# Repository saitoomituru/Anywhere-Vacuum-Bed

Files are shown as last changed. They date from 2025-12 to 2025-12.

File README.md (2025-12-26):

# どこでもバキュームベット
*Anywhere Vacuum Bed / Rubber Vacuum Bed*

*Anywhere Vacuum Bed* is an open, vacuum-fixture style project you can build anywhere with just a household vacuum and a bag—no specialty pumps needed.

掃除機と袋があれば、どこでも簡易的な真空固定・圧縮ができる
オープンソースのバキューム治具です。

With a regular shop vac and a bag, you get quick vacuum clamping or compression anywhere. The whole design is open source.

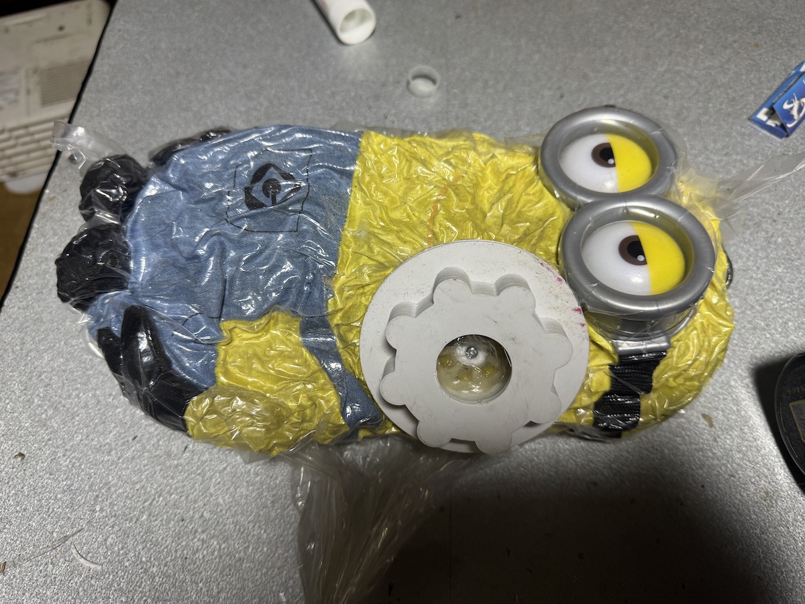
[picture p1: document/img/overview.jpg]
overview


3Dプリンタ（FDM）で再現可能。
専用シートや高価な真空ポンプは不要です。

Reproducible on common FDM printers. No custom sheets or pricey vacuum pumps required.

▶️ Demo Video (2 min)  
https://youtube.com/shorts/qQuK8cIHQdQ?si=-0dno3jXxC5wWSed

---

## 特徴

- 掃除機・ブロワ対応（真空ポンプ不要）
- 袋（PE / PP / PVC / TPU など）を消耗品として使用
- 伸びる素材・伸びない素材の両対応
- 薄く柔らかい素材でも流路を塞がない裏側リブ構造
- 逆流防止弁内蔵（初速・保持の両立）
- 工具不要で解除可能
- FDM積層の気密問題を**シリコングリス前提**で解決
- 年齢・用途を限定しない構造（使用は自己責任）

**Features (California/Texas US English)**

- Works with household vacuums and blowers—no dedicated pump.
- Uses common bags (PE/PP/PVC/TPU, etc.) as consumables.
- Handles stretchy and non-stretch films alike.
- Backside ribs keep airflow paths open even with thin, soft materials.
- Built-in check valve balances fast start-up with reliable holding.
- Release without tools.
- Airtightness assumes silicone grease to tame FDM layer leakage.
- Open form factor for all ages and uses—always at your own risk.

---

## 想定用途

- 簡易バキュームベッド / 仮固定治具
- 収納・圧縮（衣類・ぬいぐるみ等）
- ゴム・ラバー・TPU・フィルム等の柔軟素材固定
- 塗装・接着・成形前の仮固定
- 教育・FabLab・DIY用途
- 個人利用・研究用途

**Intended Uses (CA/TX English)**

- Quick vacuum bed or temporary jigging.
- Storage and compression for clothes, plush toys, and similar items.
- Holding flexible materials such as rubber, TPU, and films.
- Temporary holding before painting, bonding, or forming.
- Education, FabLab, and DIY settings.
- Personal projects and research.

⚠ **人体・物体を問わず、使用はすべて自己責任です。**
⚠ 本設計は医療・安全認証を意図したものではありません。

⚠ **Use at your own risk for people or objects.**
⚠ This design is not intended for medical or safety certification.

---

## クイックリンク（最初に読む）

- 🔧 **組み立て方法（Assembly）**
  → [`document/howto/assembly.md`](document/howto/assembly.md)

- 🧰 **使い方：伸縮性のない一般ゴミ袋**
  → [`document/howto/use_trashbag.md`](document/howto/use_trashbag.md)

- 📐 **FreeCAD 全体アセンブリ**
  → [`Assembly.FCStd`](Assembly.FCStd)

**Quick Links (read first)**

- 🔧 Assembly guide → [`document/howto/assembly.md`](document/howto/assembly.md)
- 🧰 Using non-stretch trash bags → [`document/howto/use_trashbag.md`](document/howto/use_trashbag.md)
- 📐 Full FreeCAD assembly → [`Assembly.FCStd`](Assembly.FCStd)

---

## ディレクトリ構成

```text
/
├─ README.md
├─ Assembly.FCStd              # 全体アセンブリ（FreeCAD）
├─ Bild/
│  └─ Assy/
│     └─ *.FCStd               # 各パーツ（FreeCAD）
├─ stage/
│  └─ stl/
│     └─ *.stl                 # 3Dプリント用STL
└─ document/
   ├─ img/                     # 写真・図解
   └─ howto/                   # 作り方・使用方法
      ├─ assembly.md
      └─ use_trashbag.md
```

---

## 仕組みについて（設計思想）

### 裏側リブ構造
裏側の放射リブ形状は、

- 薄い素材が吸着時に流路を塞がない
- 真空初速を維持
- 完全密閉にならず自然解除しやすい

という **安全側に倒した流路保持構造**です。

**Design Approach (CA/TX English)**

### Backside rib structure
The radiating ribs on the underside are sized so that thin materials don’t choke the airflow, startup vacuum speed stays quick, and the system can gently vent instead of locking shut—prioritizing safe flow retention.

---

## シールについて（FDM前提）

本設計では **シリコングリスの使用を前提**としています。

- FDM積層による微細リーク対策
- 材料・プリンタ個体差の吸収
- 分解・清掃・再利用が容易

**Sealing (FDM-first perspective)**

The design assumes silicone grease from the start. It handles micro-leaks from FDM layers, smooths out printer/material variances, and keeps teardown and cleaning simple.

### 塗布箇所
- 外周の袋シール溝
- **中央の逆流防止ゴム面（薄塗り）**

※ 潤滑ではなく **気密補助目的**です。

### Where to apply
- Perimeter groove that seals the bag.
- **Center check-valve rubber face (light coat).**

Note: This is for airtightness support, not for lubrication.

---

## 袋の取り付け方法（2通り）

### ① 伸びる素材（PE / TPU など）
1. 袋に **約52mmの穴**を開ける
2. 本体に袋を挟み、ネジで固定

### ② 伸びない素材（PP / 硬質PVC 等）
1. **袋に下穴は開けない**
2. そのまま本体に袋を挟んで固定
3. バキューム前に
   **中央吸入口に指を入れて袋を破る**
4. そのまま吸引開始

※ 中央弁構造により、
　破断後も袋が吸い込まれにくい設計です。

**How to attach bags (two options)**

### 1) Stretchy materials (PE/TPU, etc.)
1. Punch a **~52 mm hole** in the bag.
2. Clamp it to the body and tighten the screws.

### 2) Non-stretch materials (PP, rigid PVC, etc.)
1. **Do not pre-drill** the bag.
2. Clamp it to the body as-is.
3. Right before vacuuming, **poke the center inlet with a finger to tear the film.**
4. Start vacuuming immediately.

The center valve design keeps the torn bag from getting sucked in.

---

## 使用・解除方法（概要）

### 使用
1. 袋に対象物を入れる
2. 袋の口を縛る
3. 掃除機で吸引

### 解除
- ネジを外す
- 袋の端をつまむ
（工具不要）

**Use / Release (overview)**

### Use
1. Place the item in the bag.
2. Tie the bag closed.
3. Pull vacuum with a household vacuum.

### Release
- Remove the screws.
- Pinch the bag edge to vent (no tools needed).

---

## 3Dプリントについて

- 推奨方式：FDM
- 材質：PLA / PETG / ABS（用途に応じて）
- 機能面（シール面）は **ビルドプレート直置き推奨**
- サポート不要設計

**3D printing notes**

- Recommended process: FDM.
- Materials: PLA / PETG / ABS depending on use.
- Functional sealing faces: **print flat on the build plate**.
- Designed to avoid supports.

---

## FDM造形テック（サポート不要設計）

本設計では、**裏側リブおよび溝構造の幅をすべて 5mm 以下**に制限しています。

これは一般的なFDM 3Dプリンタにおいて、

- サポート材を使用せずに
- 安定したオーバーハング／ブリッジ造形が可能

という **実運用での再現性**を最優先した設計判断です。

**FDM build strategy (supportless)**

All underside rib and groove widths stay at or below 5 mm. On typical FDM printers, that means you can bridge and overhang without supports while keeping real-world repeatability as the top priority.

### この設計によるメリット

- サポート除去が不要
  → 表面荒れ・寸法誤差・シール面破壊を防止
- 印刷後の後処理が不要
  → プリント後すぐに使用可能
- シール面の平面性を確保
  → 真空用途における気密性向上

### Benefits of this approach

- No support removal → avoids surface roughness, dimensional drift, and seal-surface damage.
- No post-processing → use the print right away.
- Flat sealing surfaces → better airtightness for vacuum duty.

### 設計思想（FDM前提）

- 真空流路として十分な断面を確保しつつ
- 「FDMで確実に橋渡しできる寸法」を上限条件として採用

この 5mm という数値は理論値ではなく、

- ノズル径：0.4mm  
- レイヤー高：0.2〜0.28mm  
- 家庭用FDMプリンタ

という **一般的な環境での実証ベース**の設計です。

真空用途のため、微細な糸引きや軽微なたわみは
**機能的に問題にならない**ことも考慮しています。

むしろサポートを使用することで、

- シール面の精度低下
- 表面の荒れ
- 再現性の低下

が起きやすいため、本設計では **サポート不要を前提**としています。

### Design mindset (FDM-first)

- Cross-sections stay big enough for vacuum flow while capped at dimensions that bridge reliably on FDM.
- The 5 mm limit is practical, not theoretical—based on common home FDM setups (0.4 mm nozzle, 0.2–0.28 mm layers).
- For vacuum use, small strings or slight sag usually don’t matter.
- Using supports tends to hurt seal precision, roughen surfaces, and lower repeatability, so the design assumes no supports.

---

## ライセンス

本プロジェクトは **CERN Open Hardware Licence Version 2 – Permissive (CERN-OHL-P)**
の下で公開されています。

**License**

Released under the **CERN Open Hardware Licence Version 2 – Permissive (CERN-OHL-P)**.

- 商用利用可
- 改変可
- 再配布可
- 派生物の公開義務なし

⚠ **本設計の使用により生じた事故・損害について、作者は一切の責任を負いません。**

ライセンス全文：  
https://ohwr.org/cern_ohl_p_v2.txt

---

## 名前について

「どこでもバキュームベット」は  
**ドラえもん道具的に、誰でも・どこでも使える道具**  
という思想から名付けています。

用途・文脈・分野は限定していません。

---

## English (Short)

**Anywhere Vacuum Bed**  
An open-source vacuum fixture using a vacuum cleaner and plastic bags.

Released under **CERN-OHL-P v2**.  
Use at your own risk, for any object or body.

---

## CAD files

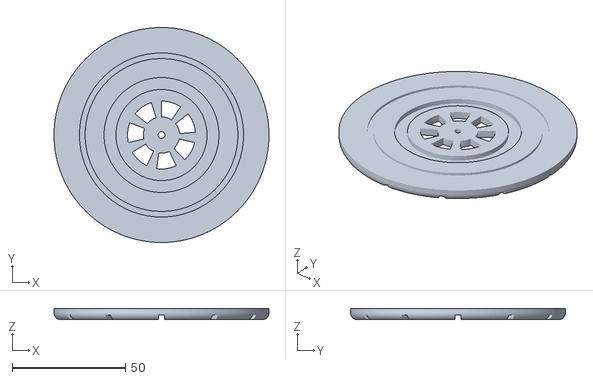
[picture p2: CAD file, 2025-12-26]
stage/stl/逆流防止弁-AssemblyPocket005.stl
95.0 x 95.0 x 5.00

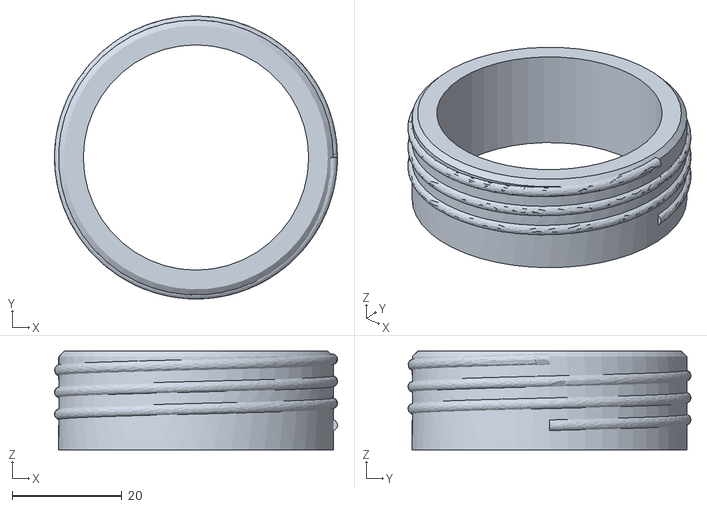
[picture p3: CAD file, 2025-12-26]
stage/stl/オスネジ-AssemblyAdditiveHelix.stl
51.5 x 51.5 x 18.0

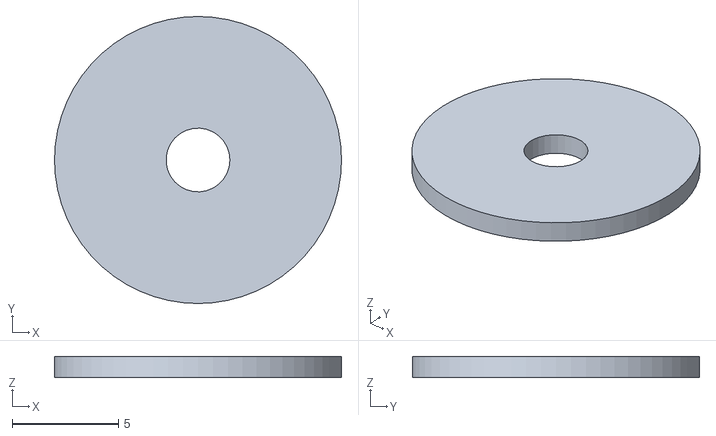
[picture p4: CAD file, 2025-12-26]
stage/stl/逆流防止弁ワッシャ-AssemblyHole.stl
13.5 x 13.5 x 1.00

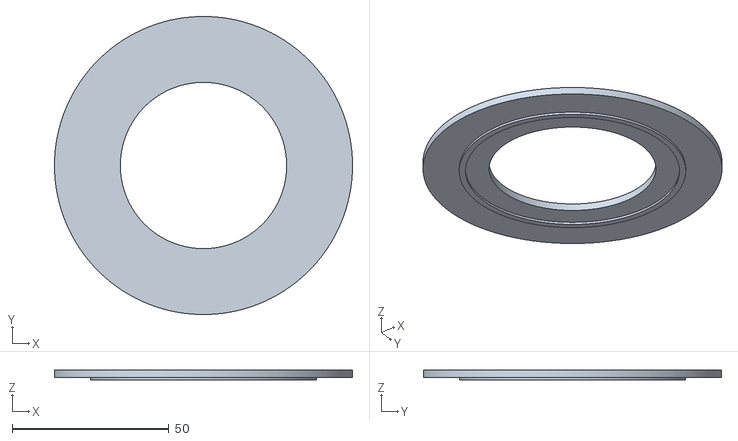
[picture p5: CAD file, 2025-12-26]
stage/stl/押さえリング-AssemblyPad001.stl
95.0 x 95.0 x 3.20

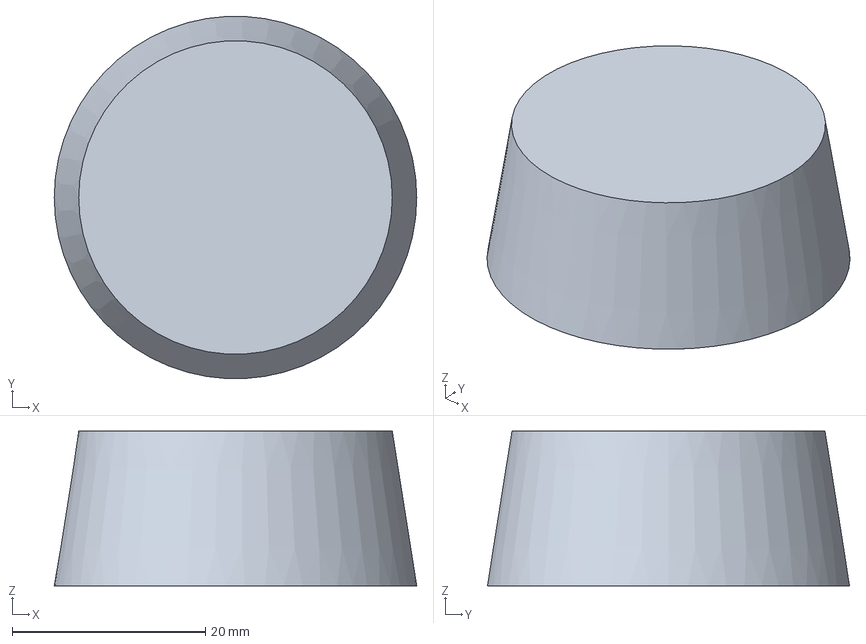
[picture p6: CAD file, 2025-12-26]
Bild/Assy/薄膜コーン.FCStd
37.5 x 37.4 x 16.0 mm

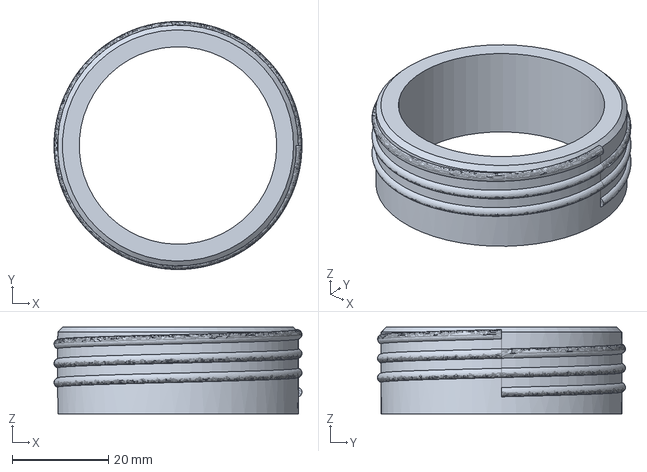
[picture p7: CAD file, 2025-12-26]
Bild/Assy/オスネジ.FCStd
51.5 x 51.5 x 18.0 mm

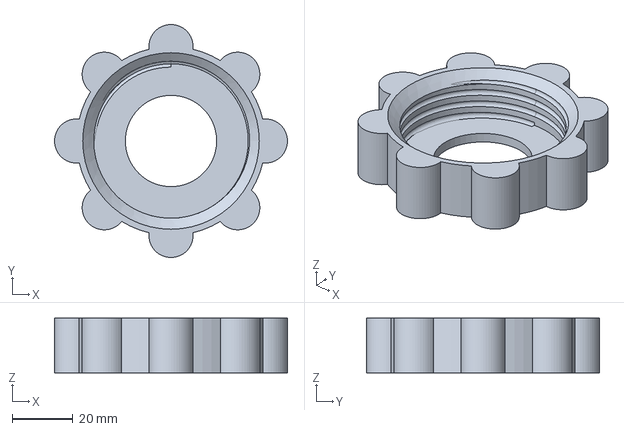
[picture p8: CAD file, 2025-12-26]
Bild/Assy/ロックナット.FCStd
76.6 x 76.6 x 18.0 mm

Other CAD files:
Assembly.FCStd
Bild/Assy/逆流防止弁.FCStd
Bild/Assy/逆流防止弁ワッシャ.FCStd
Bild/Assy/押さえリング.FCStd

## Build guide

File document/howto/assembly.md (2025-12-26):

# どこでもバキュームベット
## 作り方：逆流防止弁ユニット組み立て

本ドキュメントは、
「どこでもバキュームベット」に使用する **逆流防止弁ユニット** の
組み立て方法を示します。

本構造は **FDM 3Dプリント前提・実験用途向け** です。

# Anywhere Vacuum Bed
## Assembly: Check-valve unit (CA/TX English)

This guide shows how to assemble the **check-valve unit** for the Anywhere Vacuum Bed. The construction assumes FDM 3D printing and experimental use.

---

## 使用部品（STL）

- 逆流防止弁本体
  `逆流防止弁-AssemblyPocket005.stl`
- オスネジ部
  `オスネジ-AssemblyAdditiveHelix.stl`
- ゼロテンションワッシャ
  `付属逆流防止弁ワッシャ-AssemblyHole.stl`

**Parts (STL files)**

- Check-valve body: `逆流防止弁-AssemblyPocket005.stl`
- Male thread section: `オスネジ-AssemblyAdditiveHelix.stl`
- Zero-tension washer: `付属逆流防止弁ワッシャ-AssemblyHole.stl`

---

## 逆流防止弁（ゴム部）の仕様

### 形状
- ドーナツ状（円環）
- 外径：**45mm**
- 内径：**5mm**
- 厚み：**0.4mm**

### 素材
- **Latex（天然ゴム）**
- 検証済み素材：
  - フェティッシュ用途 高品質衣料用 Latex
  - 厚み 0.4mm

※ 本設計では **伸縮性・復元性・表面平滑性** を重視しています。

**Check-valve rubber spec (CA/TX English)**

### Shape
- Donut (torus)
- Outer diameter: **45 mm**
- Inner diameter: **5 mm**
- Thickness: **0.4 mm**

### Material
- **Latex (natural rubber)**
- Verified material:
  - High-quality clothing-grade latex for fetish use
  - Thickness 0.4 mm

The design prioritizes stretch, recovery, and surface smoothness.

#### 検証済み素材（Latex 0.4mm）

- 販売元：くらげ（KURAGE）
- 用途：高品質衣料用 Latex
- 検証厚み：0.4mm

[https://kurage.style](https://kurage.style)

#### Verified material (Latex 0.4 mm)

- Vendor: Kurage (KURAGE)
- Application: high-grade apparel latex
- Verified thickness: 0.4 mm

[https://kurage.style](https://kurage.style)

---

## 組み立て手順

### 1. ゴム弁のセット

1. 逆流防止弁本体
   `逆流防止弁-AssemblyPocket005.stl`
   の指定位置に、Latex ドーナツを配置します。
2. ゴム面は **シワ・ねじれが無い状態** にしてください。

### 1. Set the rubber valve

1. Place the latex donut on the designated seat of `逆流防止弁-AssemblyPocket005.stl`.
2. Keep the rubber smooth with **no wrinkles or twist**.

---

### 2. オスネジ部の固定

1. `オスネジ-AssemblyAdditiveHelix.stl` を
   ガイドに沿って嵌め込みます。
2. 本体とネジ部の **嵌合隙間** に
   以下のいずれかを流し込み、固定します。

#### 使用可能な接着剤
- シアノアクリレート（瞬間接着剤）
- 低粘度・浸透系接着剤（毛細管浸透タイプ）

※ ゴム面には接着剤を付着させないでください。

### 2. Fix the male-thread section

1. Fit `オスネジ-AssemblyAdditiveHelix.stl` along the guide.
2. Wick one of the following into the **fit clearance** between body and thread to lock it in place.

#### Approved adhesives
- Cyanoacrylate (instant adhesive)
- Low-viscosity penetrating adhesive (capillary type)

Do not let adhesive touch the rubber face.

---

### 3. ゼロテンションワッシャの挿入

1. `付属逆流防止弁ワッシャ-AssemblyHole.stl`
   を **ゴム弁の上に噛ませます**。
2. このワッシャは
   - ゴムの初期テンションを与えない
   - 面圧を均一化する
   目的で使用します。

### 3. Insert the zero-tension washer

1. Set `付属逆流防止弁ワッシャ-AssemblyHole.stl` **on top of the rubber valve**.
2. This washer avoids pre-tension on the rubber and evens out surface pressure.

---

### 4. M3 ネジ固定

1. M3 ネジ（**長さ10mm**）を使用
2. ナットは、弁本体側に
   **ハンダゴテで熱圧入**してください。
3. 締め込みは
   **ゴムが潰れない最小限** に留めます。

### 4. Tighten with M3 hardware

1. Use M3 screws (**length 10 mm**).
2. Heat-set the nuts into the valve body with a soldering iron.
3. Tighten only enough to avoid crushing the rubber.

---

## シール処理（重要）

本設計では **FDM積層による微細リーク対策として
シリコングリス使用を前提** としています。

## Sealing steps (important)

The design assumes **silicone grease to counter micro-leaks from FDM layers**.

### 方法A：シリコングリスのみ（簡易）
- 中央ゴム面に **薄く塗布**
- 外周シール溝にも薄塗り

### 方法B：トップコート併用（耐久重視）
1. FDM面に  
   **透明表面コート系塗料** を薄く塗布
2. 完全乾燥後
   **50cs シリコンオイル** を添付

※ 潤滑目的ではなく **気密補助目的** です。

### Option A: Silicone grease only (simple)
- **Light coat** on the center rubber face
- Light coat on the perimeter sealing groove

### Option B: With top coat (durability focused)
1. Brush a **clear surface coat** lightly onto the FDM faces.
2. After full cure, add **50 cs silicone oil**.

Note: This is for airtightness assistance, not lubrication.

---

## 動作確認

- 指で軽く吸って戻すと
  ゴム弁が **自然に開閉** する
- 強く吸うと
  ゴム面が均一に密着する
- 逆方向から吹いても
  漏れが起きにくい

## Function check

- A gentle suck-and-release with a finger makes the valve **open and close naturally**.
- Strong suction seats the rubber face evenly.
- Blowing from the reverse side is unlikely to leak.

---

## 備考

- ゴム材質・厚み変更は可能ですが
  **0.4mm Latex が最も安定** しました
- FDM積層精度・材料差により
  グリス量は調整してください
- 本設計は **人体・物体問わず自己責任利用** です

## Notes

- You can change rubber material or thickness, but **0.4 mm latex proved most stable**.
- Tune grease amount to your FDM precision and material.
- Use at your own risk for both people and objects.

---

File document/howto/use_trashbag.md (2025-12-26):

# 使用方法：伸縮性のない一般ゴミ袋を使う場合

本ドキュメントでは、
**伸縮性のない一般的なゴミ袋（PE / PP）** を使用して
「どこでもバキュームベット」を使う方法を示します。

この方法では **事前に袋へ穴を開けません**。

# How to use: non-stretch trash bags (CA/TX English)

This guide covers using **standard non-stretch trash bags (PE/PP)** with the Anywhere Vacuum Bed. With this method, **you do not pre-punch the bag**.

---

## 使用部品（STL）

- 逆流防止弁本体
  `逆流防止弁-AssemblyPocket005.stl`
- オスネジ
  `オスネジ-AssemblyAdditiveHelix.stl`
- 逆流防止弁ワッシャ（ゼロテンション）
  `逆流防止弁ワッシャ-AssemblyHole.stl`
- 押さえリング
  `押さえリング-AssemblyPad001.stl`
- ロックナット
  `ロックナット-AssemblySubtractiveHelix.stl`

**Parts (STL files)**

- Check-valve body: `逆流防止弁-AssemblyPocket005.stl`
- Male thread: `オスネジ-AssemblyAdditiveHelix.stl`
- Check-valve washer (zero tension): `逆流防止弁ワッシャ-AssemblyHole.stl`
- Retaining ring: `押さえリング-AssemblyPad001.stl`
- Locknut: `ロックナット-AssemblySubtractiveHelix.stl`

---

## 手順

### 手順1：袋の内側に弁ユニットを入れる

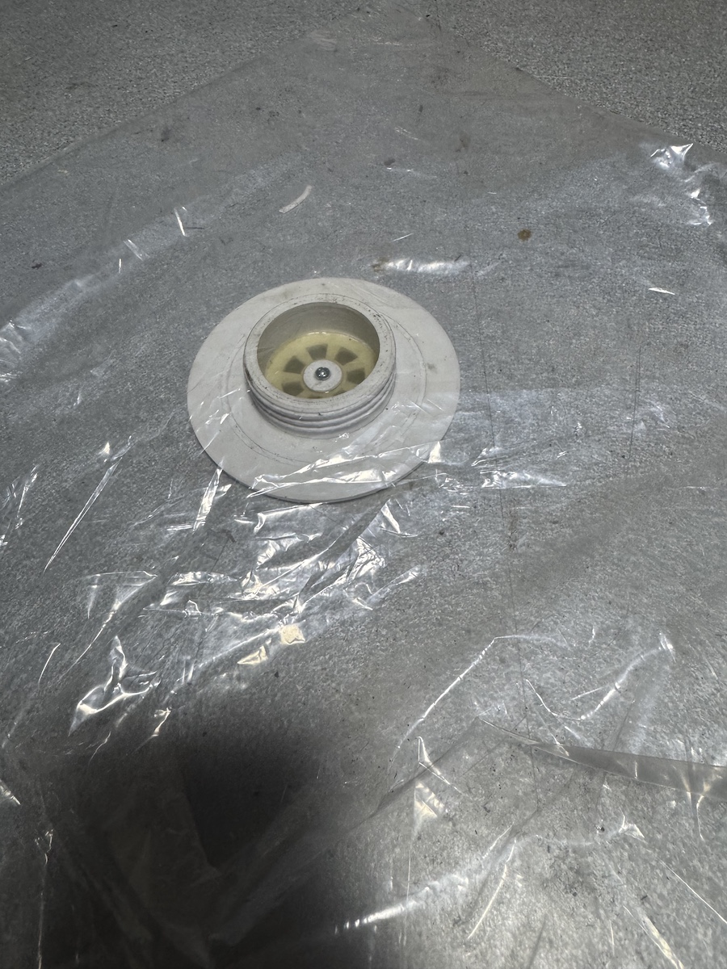
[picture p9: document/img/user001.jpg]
user001


袋の**内側**に、`assembly.md` に従って **事前に組み立て済み** の
逆流防止弁ユニットをセットします。

#### 使用部品
- 逆流防止弁ワッシャ  
  `逆流防止弁ワッシャ-AssemblyHole.stl`
- 逆流防止弁本体  
  `逆流防止弁-AssemblyPocket005.stl`
- オスネジ  
  `オスネジ-AssemblyAdditiveHelix.stl`
- Latex 弁（ドーナツ状）

> 組み立て方法の詳細は  
> **`assembly.md` を熟読し、必ず先に組み立ててください。**

※ この時点では **袋に穴は開けません**。

### Step 1: Place the valve unit inside the bag

Insert the pre-assembled check-valve unit (per `assembly.md`) on the **inside** of the bag.

#### Parts used
- Check-valve washer: `逆流防止弁ワッシャ-AssemblyHole.stl`
- Check-valve body: `逆流防止弁-AssemblyPocket005.stl`
- Male thread: `オスネジ-AssemblyAdditiveHelix.stl`
- Latex valve (donut)

> Review `assembly.md` in detail and complete assembly first.

No holes are made in the bag at this stage.

---

---

### 手順2：袋の外側から押さえリングを挿入

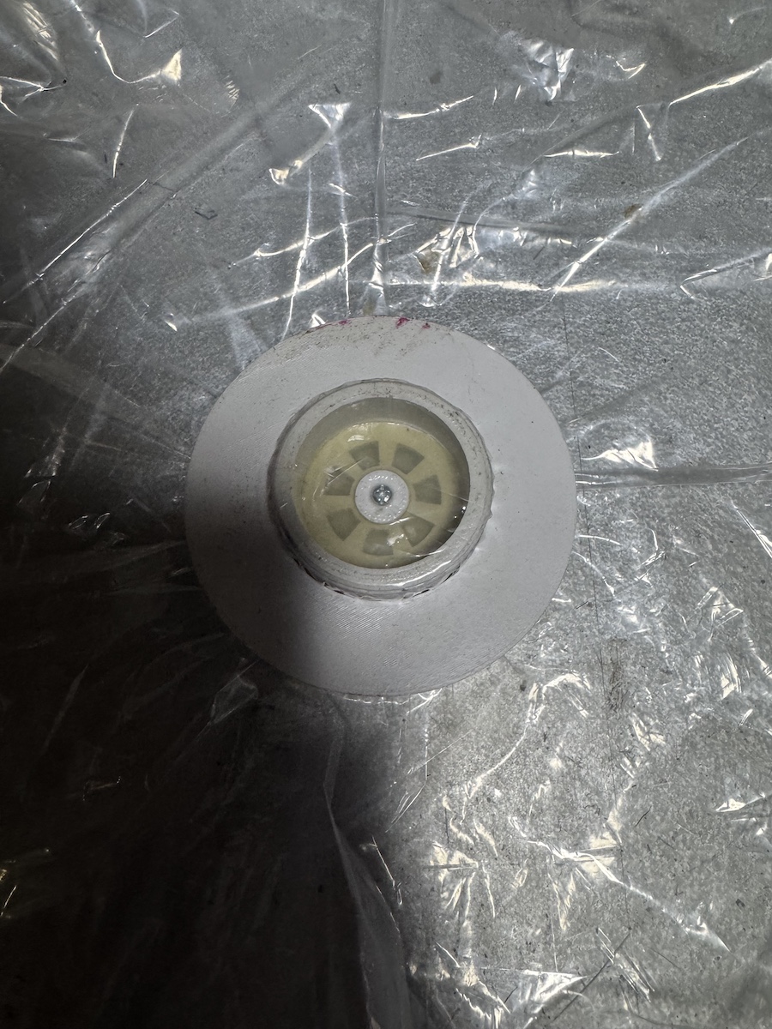
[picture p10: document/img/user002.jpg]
user002


袋の**外側**から、  
`押さえリング-AssemblyPad001.stl` を押し当てます。

- 袋は部品の間で**挟み込まれる構造**
- 袋素材がそのままシールとして機能します

### Step 2: Add the retaining ring from outside the bag

From the **outside**, press `押さえリング-AssemblyPad001.stl` against the bag.

- The bag is **clamped between the parts**.
- The bag material itself acts as the seal.

---

### 手順3：ロックナットで固定

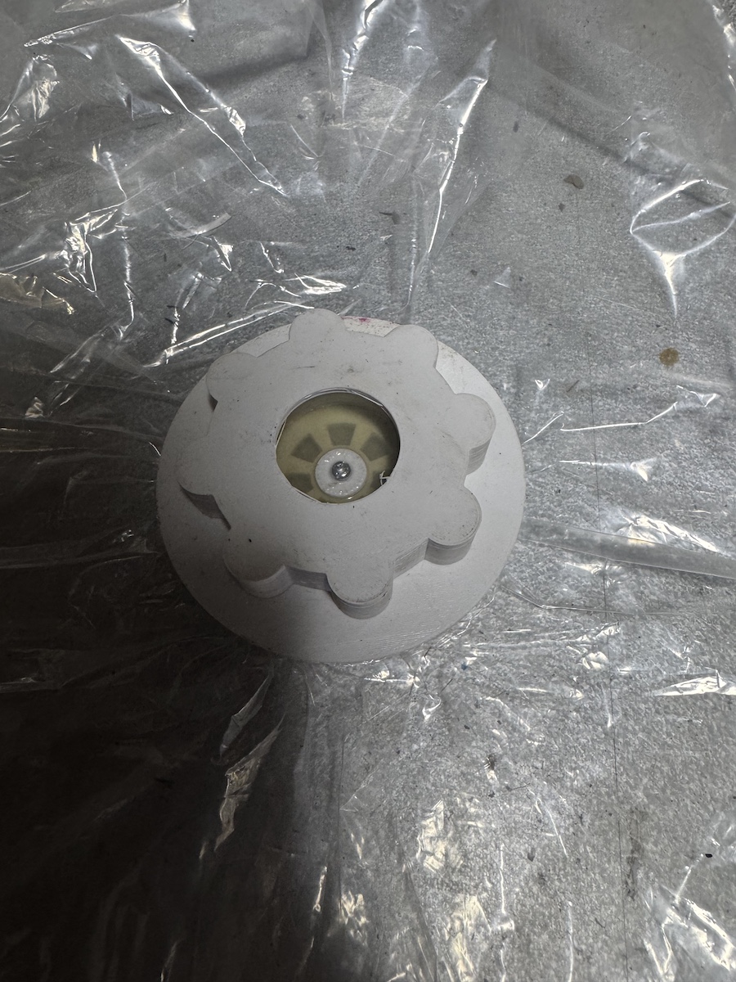
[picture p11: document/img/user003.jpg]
user003


袋の外側から  
`ロックナット-AssemblySubtractiveHelix.stl` をねじ込み、固定します。

- 強く締めすぎない
- 袋が均一に挟まれていることを確認

### Step 3: Lock with the nut

Thread `ロックナット-AssemblySubtractiveHelix.stl` from the outside and secure it.

- Do not overtighten.
- Confirm the bag is clamped evenly.

---

### 手順4：内容物を入れて袋を縛る

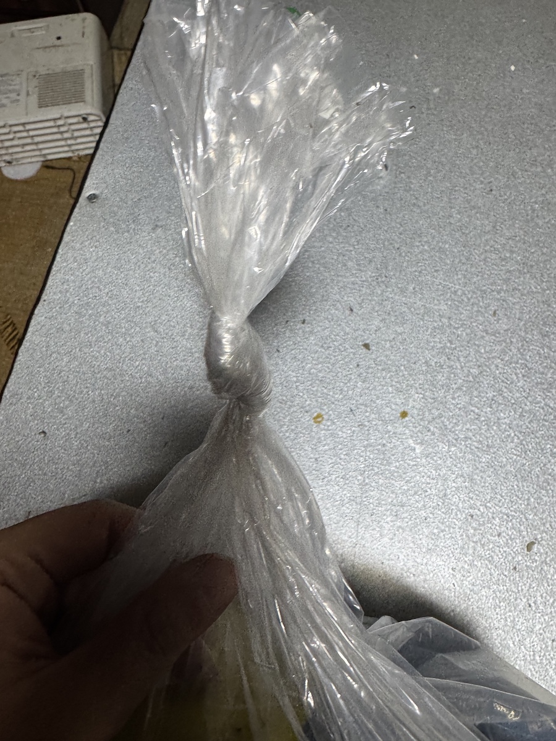
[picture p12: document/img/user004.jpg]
user004


- 袋の中に内容物を入れます
- 袋の口を縛り、密閉します

この時点では、
**袋はまだ完全に密閉された状態**です。

### Step 4: Load the contents and tie the bag

Place the contents inside, then tie the bag closed. At this point the bag remains fully sealed.

---

### 手順5：中央を破って吸引開始

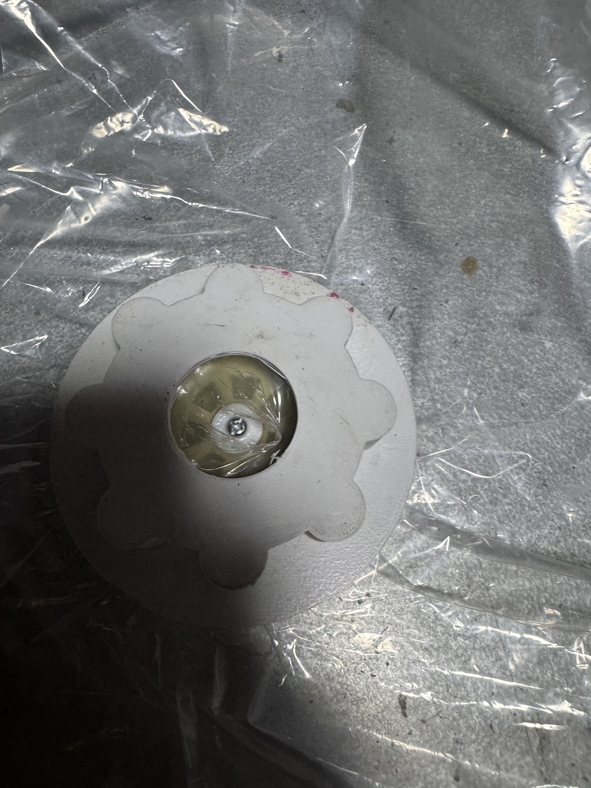
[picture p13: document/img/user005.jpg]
user005


吸引前に、  
**中央吸入口に指を入れて袋を破ります**。

- 事前の穴あけ不要
- 吸入口位置で自然に破断
- 破断後も袋が吸い込まれにくい構造

そのまま掃除機を接続し、吸引を開始します。

### Step 5: Tear the center and start vacuuming

Before pulling vacuum, **poke the center inlet with your finger to tear the film**, then connect the vacuum and start suction.

---

## 補足

- 伸縮性のない袋でも問題なく使用できます
- 破断は **必ず吸引直前** に行ってください
- シリコングリスを併用すると気密が安定します
- 解除時は、ロックナットを外して袋端をつまむだけです

## Tips

- Non-stretch bags work fine.
- Always tear **right before** pulling vacuum.
- Silicone grease helps stabilize the seal.
- To release, remove the locknut and pinch the bag edge.

---

## 注意

- 使用は **自己責任** です
- 人体・物体を問わず、
  本設計は安全認証を意図したものではありません

## Warnings

- Use entirely at your own risk.
- This design is not intended for any certified safety use with people or objects.

---

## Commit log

2025-12-26 初回コミット
    [Assembly.FCStd, オスネジ-AssemblyAdditiveHelix.stl, オスネジ.FCStd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]
2025-12-26 ドキュメント整理
2025-12-26 READMEずれ直し
2025-12-26 デモ動画更新・README抜け修正
2025-12-26 印刷設計のREADME追加
